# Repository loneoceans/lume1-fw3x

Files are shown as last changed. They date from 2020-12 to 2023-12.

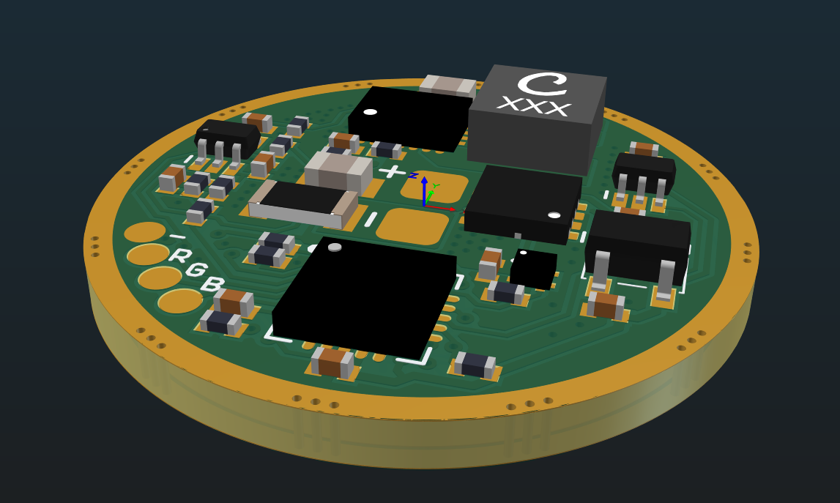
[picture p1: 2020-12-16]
physical/Rev B/lume1_fw3x_AssemblyRender2.png

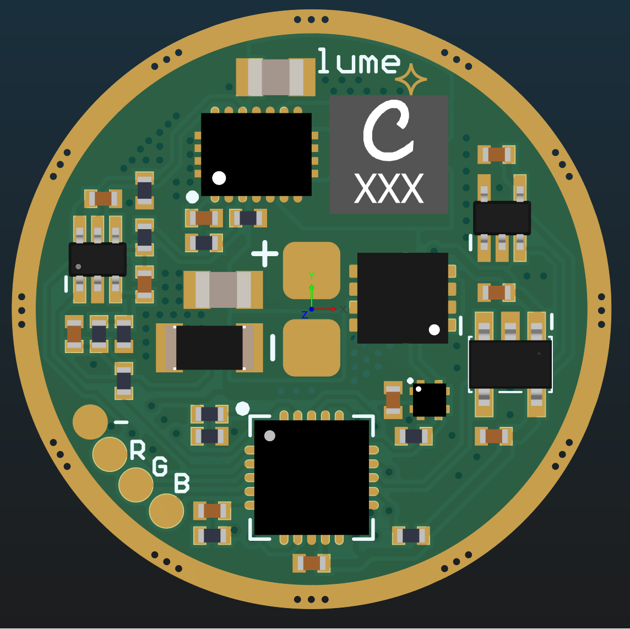
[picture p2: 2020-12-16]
physical/Rev B/lume1_fw3x_AssemblyRender1.png

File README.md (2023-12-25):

# lume1-fw3x-anduril
>**Update Dec 2023**
>
>LUME1-FW3X support has been added to the main Anduril repository here: https://github.com/ToyKeeper/anduril/tree/trunk/hw/lumintop/fw3x-lume1
>
>This repository is deprecated, please visit the link above for fresh builds of the newest version of Anduril.

Anduril 1 & 2 firmware (Atmel Studio 7) for Lume1-FW3X Driver

Hardware Revision B (lastest driver PCB has date 06/20)

lume1 Driver

* For more information: www.lonoceans.com/labs/
* Anduril by TK: https://launchpad.net/flashlight-firmware
* Community thread: http://budgetlightforum.com/node/71616

OSH

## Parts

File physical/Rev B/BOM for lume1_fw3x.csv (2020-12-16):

Designator | Quantity | Footprint | Value | Manufactuer Primary Part Number | Alternate Part Number | Description
C1 | 1 | 0402 CAPACITOR | 220p 50V X5R 402 | UMK105BJ221KV-F | CC0402KRX7R9BB221 | 0402 Capacitor
C2, C3, C4, C5 | 4 | 0402 CAPACITOR | 0.1u 16V X7R 402 | CL05B104KO5NFNC | CL05B104KO5NFNC | 0402 Capacitor
C6 | 1 | 0402 CAPACITOR | 1u 10V X6S 402 | LMK105C6105MV-F | GRM155C81A105KA12D | 0402 Capacitor
C7, C8, C9, C10 | 4 | 0402 CAPACITOR | 2.2u 10V X5R 402 | LMK105BJ225MV-F | GRM155C81E225ME11D | 0402 Capacitor
C11, C12 | 2 | 0805 CAPACITOR | 47u 10V 0805 X5R | C2012X5R1A476M125A | GRM21BR61A476ME15L | 0805 Capacitor
L1 | 1 | XFL4020 INDUCTOR | Inductor Coilcraft XFL | XGL4020-152MEC |  | Coilcraft DCR Shielded Power Inductor
Q1 | 1 | POWERPAK 1212-8S CD DUAL | 25V 30A Dual Common Drain MOSFET | SISF02DN-T1-GE3 | SISF00DN-T1-GE3 | Common Drain Dual N-Channel MOSFET
R1 | 1 | 1206 RESISTOR | 20mR 1206 1% 1W | LVT12R0200FER |  | 1206 Metal Element Resistor
R2 | 1 | 0402 RESISTOR | 100R 1% 402 | RC0402FR-07100RL |  | 0402 1% Resistor
R3, R4, R5, R6 | 4 | 0402 RESISTOR | 10k 1% 402 | RC0402FR-0710KL |  | 0402 1% Resistor
R7 | 1 | 0402 RESISTOR | 51k 1% 402 | RC0402FR-0751KL |  | 0402 1% Resistor
R8, R9, R10, R11 | 4 | 0402 RESISTOR | 100k 1% 402 | RC0402FR-07100KL |  | 0402 1% Resistor
R12 | 1 | 0402 RESISTOR | 249k 1% 402 | RC0402FR-07249KL |  | 0402 1% Resistor
R13 | 1 | 0402 RESISTOR | 392k 1% 402 | RC0402FR-07392KL |  | 0402 1% Resistor
U1 | 1 | VSON14 DSJ 4X3MM | Switching Regulator TPS63020 | TPS63020DSJR |  | 4A Synchronous Buck Boost Converter TI
U2 | 1 | QFN 20M1 | ATTINY1634 QFN20 4X4mm | ATTINY1634-MU-ND |  | 8-bit Atmel tinyAVR 16kB Flash
U3 | 1 | SC70-6 | Op Amp LTC2066 | LTC2066ISC6#TRMPBF |  | SC70-6 Op Amp with Shutdown
U4 | 1 | SC70-5 | Temperature Sensor MCP9700A | MCP9700AT-E/LT |  | Low-Power Linear Active Thermistor IC
U5 | 1 | SOT23-5 | Regulator TPS706 SOT23 | TPS70625DBVR |  | TPS706 SOT23-5 Voltage Regulator
U6 | 1 | QFN4 FT MICREL | MIC5019 Nfet Driver | MIC5019YFT-TR |  | High Side N FET Driver with Charge Pump

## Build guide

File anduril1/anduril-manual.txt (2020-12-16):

Anduril User Manual
-------------------

Anduril is an open-source firmware for flashlights, distributed under 
the terms of the GPL v3.  The sources can be obtained here:

  http://tiny.cc/TKAnduril
  https://bazaar.launchpad.net/~toykeeper/flashlight-firmware/trunk/files/head:/ToyKeeper/spaghetti-monster/anduril/

Quick Start
-----------

After putting a battery in the light and tightening the parts together, 
the light should quickly blink once to confirm it has power and is now 
operational.  After that, basic usage is simple:

  - Click to turn the light on or off.
  - Hold the button to change brightness.
  - Release and hold again to change brightness the other way.

That is all the user needs to know for basic use, but there are many 
more modes and features available for people who want more.

Before reading the rest of this manual, it is recommended that users 
look at the Anduril UI diagram, which should be provided along with the 
flashlight.

Ramping / Stepped Ramping Modes
-------------------------------

Anduril's normal operation mode uses a smooth ramp or a stepped ramp, 
depending on which style the user prefers.

Each ramp has its own settings -- floor (lowest level), ceiling (highest 
level), and the stepped ramp can also have a configurable number of 
steps.

There are four ways to access this mode when the light is off:

  - Click: Turn on at the memorized brightness.
  - Hold: Turn on at the floor level.  The light should give a very 
    subtle dark blink when the user can let go of the button to stay at 
    the floor, or keep holding the button to ramp up.
  - 2 clicks: Turn on at the ceiling level.
  - Click, hold: Turn on at the ceiling level, then ramp down.

While the light is on, a few basic actions are available:

  - Click: Turn off.
  - 2 clicks: Go to or from turbo (full power).
  - Hold: Change brightness (up).  If the button was released less than 
    a second ago, or if it's already at the ceiling, it goes down 
    instead.
  - Click, hold: Change brightness (down).
  - 3 clicks: Switch to the other ramp.
  - 4 clicks: Go to ramp config mode.
  - 5 clicks: Activate manual memory and save the current brightness.
  - 5 clicks, but hold the last click: Go back to automatic memory.

The "automatic" vs "manual" memory modes change the level the light goes 
to with 1 click from off.  In automatic mode, it uses the last 
brightness the user ramped to.  In manual mode, it uses the brightness 
the user explicitly saved with 5 clicks.

Other Modes
-----------

Anduril has several other modes too.  To access these, press the button 
more than 2 times when the light is off:

  - 3 clicks: Access the blinky / utility modes.
  - Click, click, hold: Access the strobe modes.
  - 4 clicks: Lockout mode.
  - 5 clicks: Momentary mode.
  - 6 clicks: Muggle mode.

Blinky / Utility Modes
----------------------

Click 3 times from Off to access Anduril's blinky / utility modes.  This 
always starts at battery check and the user can proceed to other blinky 
modes from there.  The sequence is:

  1. Battery check.
  2. Sunset mode.
  3. Beacon mode.
  4. Temperature check.

In all of these modes, some basic actions are available:

  - Click: Turn off.
  - 2 clicks: Next blinky mode.

Additionally, in beacon and temperature check modes:

  - 4 clicks: Go to the beacon config mode or thermal config mode.

In more detail, this is what each blinky / utility mode does:

  1. Battery check.

     Blinks out the battery voltage per cell.  Full is 4.2V, empty is 
     about 3.0V.  The light blinks the whole-number digit first, pauses, 
     then blinks out the "tenths" digit.  Then a longer pause, and it 
     repeats.
     So for 4.2V, it would be "blink-blink-blink-blink .. blink-blink".

     A "zero" digit is represented by a very quick blink.

  2. Sunset mode.

     This starts at a low level, then dims gradually for an hour, and 
     then shuts off.  It is intended for use when going to bed.

  3. Beacon mode.

     Blinks at a slow speed.  The light stays on for half a second, and 
     then stays off until the next blink.  The brightness and the number 
     of seconds between pulses are configurable:

       - Brightness is the user's last-ramped level, so set this in 
         ramping mode before starting beacon mode.

       - Speed is configured in beacon config mode.  Click 4 times to 
         enter beacon config mode, wait for the light to stutter, then 
         click to enter the number of seconds per blink.  For example, 
         to do a 10-second alpine beacon, click 10 times.

  4. Temperature check.

     Blinks out the current temperature in degrees C.  This number 
     should be pretty close to what a real thermometer says.  If not, it 
     would be a good idea to click 4 times to enter thermal config mode, 
     and calibrate the sensor.

     Thermal config mode has two settings:

     - Current temperature.  Click once per degree C to calibrate the 
       sensor.  For example, if the ambient temperature is 21 C, then 
       click 21 times.

     - Temperature limit.  This sets the maximum temperature the light 
       can reach before it will start doing thermal regulation to keep 
       itself from overheating.  Click once per degree C above 30.  For 
       example, to set the limit to 50 C, click 20 times.  The default 
       is 45 C, and the highest value it will allow is 70 C.

Strobe / Mood Modes
-------------------

Anduril includes a few extra modes for a variety of purposes:

  - Candle mode
  - Bike flasher
  - Party strobe
  - Tactical strobe
  - Lightning storm mode

Click 3 times from Off to access these, but hold the third click for a 
moment.  Click, click, hold.  The last-used strobe mode is remembered, 
so it will return to whichever one you used last.

In all of these modes, a few actions are available:

  - Click: Turn off.
  - 2 Clicks: Next strobe / mood mode.
  - Hold: Increase brightness, or strobe faster.  (except lightning)
  - Click, hold: Decrease brightness, or strobe slower.  (except lightning)

Additionally, candle mode has one more action:

  - 3 clicks: Add 30 minutes to the timer.

In more detail, here is what each mode does:

  - Candle mode

    Brightness changes randomly in a pattern resembling a candle flame.  
    If a timer is set, it will run until the timer expires, then get 
    dimmer for one minute, then sputter and turn itself off.  Without a 
    timer, candle mode runs until the user turns it off.  Brightness is 
    configurable.

  - Bike flasher

    Runs at a medium level, but stutters to a brighter level once per 
    second.  Designed to be more visible than a normal ramping mode, but 
    otherwise works mostly the same.  Brightness is configurable.

  - Party strobe

    Motion-freezing strobe light.  Can be used to freeze spinning fans 
    and falling water.  Speed is configurable.

  - Tactical strobe

    Disorienting strobe light.  Can be used to irritate people.  Speed 
    is configurable, and the duty cycle is always 33%.

  - Lightning storm mode

    Flashes at random brightness and random speed to simulate lightning 
    strikes during a busy lightning storm.  Do not look directly at the 
    flashlight when this mode is running, because it may suddenly go to 
    full power without warning.

Lockout Mode
------------

Click 4 times from Off to enter Lockout mode.  This makes the light safe 
to carry in a pocket or a bag or anywhere else the button might be 
pressed by accident.

To exit lockout mode, click 4 times.  The light should blink briefly and 
then return to the regular "off" mode.

Lockout mode also doubles as a momentary moon mode, so the user can do 
quick tasks without having to unlock the light.  The brightness in 
lockout mode has two levels:

  - Hold: light up at the floor level of the current ramp.
  - Click, Hold: light up at the floor level of the other ramp.

Momentary Mode
--------------

Click 5 times from Off to enter Momentary mode.  This locks the 
flashlight into a single-mode interface where the LEDs are only on when 
the button is held down.  It is intended for Morse code, light painting, 
and other tasks where the light should be on only for a short time and 
probably in a pattern.

Momentary mode does either a steady brightness level or a strobe.  To 
select which one, go to the mode you want to use, adjust the brightness 
and speed and other settings, then turn the light off.  Then click 5 
times to enter momentary mode.

Supported momentary modes are steady (normal ramping mode) and strobes 
(everything in the "strobe" mode group).

In steady mode, brightness is the last-ramped level, so adjust that 
before entering momentary mode.

In momentary strobe mode, the settings are copied from the last-used 
strobe mode, such as party strobe, tactical strobe, or lightning.

To exit this mode, physically disconnect power by unscrewing the tailcap 
or battery tube.

Muggle Mode
-----------

Click 6 times from Off to enter Muggle mode.  This is a simpler and 
less-bright interface which makes the light relatively safe to lend to 
children or other people who could use the light unsafely.

In Muggle mode, there are only a few available actions:

  - Click: Turn the light on or off.
  - Hold: Change brightness.
  - 6 clicks: Exit Muggle mode.

The brightness in this mode usually goes from about 10 lm to 300 lm.

Muggle mode is remembered even after changing the battery.  This helps 
prevent children from exiting the mode by unscrewing the tailcap.  
However, be sure to supervise children whenever they are using any 
powerful tools, including a bright flashlight.

Note: If the light steps down in muggle mode, it probably needs to have 
the temperature sensor calibrated.  Use thermal config mode to do this.

Configuration Modes
-------------------

Every config mode has the same interface.  The menu has one or more 
options the user can configure, and it will go through them in order.  
For each menu item, the light will follow the same pattern:

  - Blink one or more times, corresponding to the item number.

  - Stutter or "buzz" quickly between two brightness levels for a few 
    seconds.  This indicates that the user can click one or more times 
    to enter a number.  It will keep buzzing until the user stops 
    clicking, so there is no need to hurry.

  - Pause, and then go to the next option.

After the light has gone through all of the menu options, it should 
return to whatever mode the light was in before entering the config 
mode.

If the user doesn't press a button during a menu item's "buzz" phase, 
that item remains unchanged from its previous value.

Ramp Config Mode
----------------

While the light is on in a ramping mode, click 4 times to enter the 
config mode for the current ramp.

For smooth ramping mode, there are two menu options:

  1. Floor.  (default = 1/150)
  2. Ceiling.  (default = 120/150)

For the stepped ramping mode, there are three menu options:

  1. Floor.  (default = 20/150)
  2. Ceiling.  (default = 120/150)
  3. Number of steps.  (default = 7)

To configure the floor level, click the button equal to the number of 
ramp levels (out of 150) at which the floor should be.  To set the 
lowest possible level, click once.

To configure the ceiling level, each click goes one level lower.  So 1 
click sets the highest possible level, 2 clicks is the 2nd-highest, 3 
clicks is the 3rd-highest level, etc.  To set the default of 120/150, 
click 31 times.

When configuring the number of steps, the value can be anything from 2 
to 150.

Protection Features
-------------------

Anduril includes low voltage protection (LVP) and thermal regulation.

LVP makes the light step down to a lower level when the battery is low, 
and if the light is already at the lowest level, it shuts itself off.  
This activates at 2.8V.  LVP adjustments happen suddenly, in large 
steps.

Thermal regulation attempts to keep the light from overheating, and 
otherwise adjusts output to stay as close as possible to the 
user-configured temperature limit.  Thermal adjustments happen 
gradually, in steps so small they are difficult for humans to perceive.

Aux LEDs / Button LEDs
----------------------

Some lights have aux LEDs or button LEDs.  These can be configured to do 
different things while the main emitters are off.  There is one aux LED 
mode for the regular "off" mode, and another aux LED mode for "lockout" 
mode.  This allows the user to see at a glance whether the light is 
locked.

Aux LED modes typically include:

  - Off
  - Low
  - High
  - Blinking

To configure the aux LEDs, go to the mode you want to configure and then 
click the button a few times:

  - Off mode: 7 clicks.
  - Lockout mode: 3 clicks.

This should change the aux LEDs to the next mode supported on this 
light.

If the aux LEDs can change color, there are additional actions to change 
the color.  It is the same as above, but hold the button on the last 
click and then let go when the desired color is reached.

  - Off mode: 7 clicks, but hold the last click.
  - Lockout mode: 3 clicks, but hold the last click.

For lights with a button LED, the button LED typically stays on while 
the main emitters are on.  Its brightness level is set in a way which 
mirrors the main LED -- off, low, or high.

For lights with front-facing aux LEDs, the aux LEDs typically stay off 
when the main emitters are on, and when the light is otherwise awake.  
The aux LEDs on most lights only turn on when the light is asleep.

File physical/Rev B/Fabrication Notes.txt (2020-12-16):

Contact: Guangyan, loneoceans@gmail.com
Project: lume1_fw3x_revb
Date: 30 Jun 2020

========= FABRICATION SPECIFICATIONS ========= 
Layers 			2
Material 		FR-4
PCB Finished Thickness	1.6mm
Finished Copper Weight	1oz
Minimum Trace Width	6mil
Minimum Spacing		6mil
Minimum Via Drill	10mil (0.254mm)
Minimum Annular Ring	5mil
Via Process		Mix of Tented and Untented
Number of Drills	149
Silkscreen Min Width	4mil
Silkscreen Colour	White
Soldermask Colour	Red
Surface Finish		ENIG 1u"
Assembly		Only Top Side
Components		33
Unique BOM Items	20
Solder Paste		Leaded Solder
RoHS			Not Required
Board Type		Individual Route-Out
===============================================

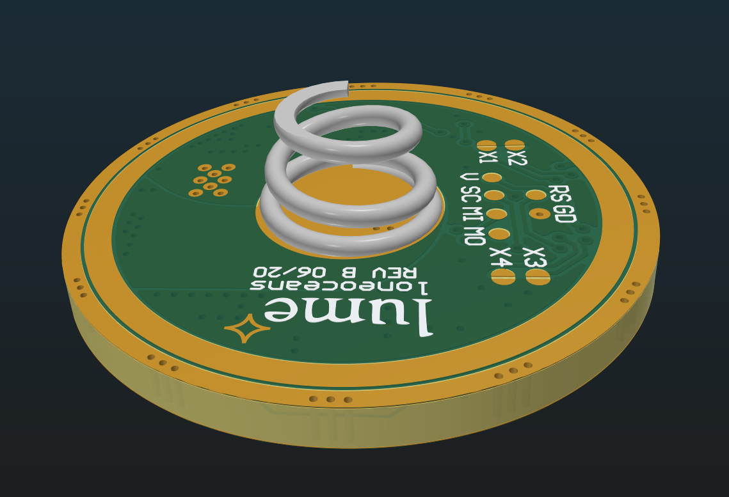
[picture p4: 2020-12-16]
physical/Rev B/lume1_fw3x_AssemblyRender3.png

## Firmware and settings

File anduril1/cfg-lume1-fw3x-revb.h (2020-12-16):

/* lume1 for FW3x config options for Anduril
 * Constant current Buck-Boost + FET driver
 * For more information: www.loneoceans.com/labs/
 * Datasheets:
 * - 1634: http://ww1.microchip.com/downloads/en/DeviceDoc/Atmel-8303-8-bit-AVR-Microcontroller-tinyAVR-ATtiny1634_Datasheet.pdf
 * - Manual: https://bazaar.launchpad.net/~toykeeper/flashlight-firmware/fsm/view/head:/ToyKeeper/spaghetti-monster/anduril/anduril-manual.txt
 * - Repository: https://code.launchpad.net/~toykeeper/flashlight-firmware
 */

#include "hwdef-lume1-fw3x-revb.h"
// ATTINY: 1634

// ##################################################
// ##               THERMAL CONFIG                 ##
// ##################################################

// NOTES: Anduril1 updated with Enable Pin support handling
// NOTES: Anduril1 updated to support external temp sensor handling (see HWCFG for formulas)

#define USE_THERMAL_REGULATION

// set this light for 50C thermal ceiling
#undef DEFAULT_THERM_CEIL
#define DEFAULT_THERM_CEIL 50
//#define MAX_THERM_CEIL 70 // default

// drop from turbo at therm_ceil+TURBO_TEMP_EXTRA
#define TURBO_TEMP_EXTRA 3 // in celsius

// optional, makes initial turbo step-down faster so first peak isn't as hot
// FET mode can run very very hot, so be extra careful
//#define THERM_HARD_TURBO_DROP

// stop panicking at ~85% regulated power or ~750 lm
#define THERM_FASTER_LEVEL 140

// respond to thermal changes faster
#define THERMAL_WARNING_SECONDS 3
#define THERMAL_UPDATE_SPEED 1
#define THERM_PREDICTION_STRENGTH 4
//#define THERM_RESPONSE_MAGNITUDE 128

// easier access to thermal config mode, similar to Emisar, Noctigon
#define USE_TENCLICK_THERMAL_CONFIG

#define THERM_CAL_OFFSET 0  // not needed due to external sensor

// do not recalibrate light temperature to 21C upon factory reset!
// Lume driver has a calibrated temperature sensor already
// modified main.c at line 2534
#define NO_TEMP_CAL_DURING_RESET


// ##################################################
// ##                 RAMP CONFIG                  ##
// ##################################################

// ../../bin/level_calc.py cube 1 149 7135 0 0.5 1000, with 0 appended to the end.
// for FET PWM (PWM2), all values are 0, except for last value of 1023
// (with max_pwm set to 1023)
#define RAMP_LENGTH 150
//#define PWM1_LEVELS 0,0,0,0,1,1,1,1,2,2,2,3,3,4,4,5,5,6,7,7,8,9,10,11,12,13,14,15,16,17,19,20,22,23,25,26,28,30,32,34,36,38,40,42,45,47,49,52,55,58,60,63,66,70,73,76,80,83,87,91,94,98,102,107,111,115,120,124,129,134,139,144,150,155,160,166,172,178,184,190,196,203,209,216,223,230,237,244,252,259,267,275,283,291,299,308,316,325,334,343,353,362,372,382,392,402,412,423,433,444,455,466,478,489,501,513,525,538,550,563,576,589,602,616,630,644,658,672,687,701,716,731,747,762,778,794,810,827,844,861,878,895,913,930,948,967,985,1004,1023,0
#define PWM1_LEVELS 1,1,1,1,2,2,2,2,3,3,3,4,4,5,5,6,6,7,8,8,9,10,11,12,13,14,15,16,17,18,20,21,23,24,26,27,29,31,33,35,37,39,41,43,45,48,50,53,56,58,61,64,67,70,74,77,80,84,88,91,95,99,103,108,112,116,121,125,130,135,140,145,150,156,161,167,173,178,184,191,197,203,210,217,223,230,238,245,252,260,268,275,283,292,300,308,317,326,335,344,353,363,372,382,392,402,413,423,434,445,456,467,478,490,502,514,526,538,551,563,576,589,603,616,630,644,658,672,687,702,717,732,747,763,778,794,811,827,844,861,878,895,913,931,949,967,985,1004,1023,0
#define PWM2_LEVELS 0,0,0,0,0,0,0,0,0,0,0,0,0,0,0,0,0,0,0,0,0,0,0,0,0,0,0,0,0,0,0,0,0,0,0,0,0,0,0,0,0,0,0,0,0,0,0,0,0,0,0,0,0,0,0,0,0,0,0,0,0,0,0,0,0,0,0,0,0,0,0,0,0,0,0,0,0,0,0,0,0,0,0,0,0,0,0,0,0,0,0,0,0,0,0,0,0,0,0,0,0,0,0,0,0,0,0,0,0,0,0,0,0,0,0,0,0,0,0,0,0,0,0,0,0,0,0,0,0,0,0,0,0,0,0,0,0,0,0,0,0,0,0,0,0,0,0,0,0,1023

#define DEFAULT_LEVEL 56
#define MAX_1x7135 77   // approximately 500mA equivalent

//#define HALFSPEED_LEVEL 14
//#define QUARTERSPEED_LEVEL 5

// turn on BuckBoost from level 1 to 149, but not 150
// Level 150 is when BuckBoost is off and FET is ON 100%
#define LED_ENABLE_PIN_LEVEL_MIN 1
#define LED_ENABLE_PIN_LEVEL_MAX 149

// the entire ramp is regulated; don't blink halfway up
#ifdef BLINK_AT_RAMP_MIDDLE
#undef BLINK_AT_RAMP_MIDDLE
#endif

// don't slow down at low levels; this isn't that sort of light
// (it needs to stay at full speed for the 10-bit PWM to work)
#ifdef USE_DYNAMIC_UNDERCLOCKING
#undef USE_DYNAMIC_UNDERCLOCKING
#endif

#define RAMP_SMOOTH_FLOOR 1
#define RAMP_SMOOTH_CEIL 149	// Level 150 is when BuckBoost is off and FET is ON 100%
// 10, 30, [50], 70, 90, 110, 130
#define RAMP_DISCRETE_FLOOR 10
#define RAMP_DISCRETE_CEIL RAMP_SMOOTH_CEIL
#define RAMP_DISCRETE_STEPS 7

// Muggle mode: Goal from about ~10 lumens to about ~300+ lumens
// In this case, ramp number 99 is about 1A to the driver
#define MUGGLE_FLOOR RAMP_DISCRETE_FLOOR
#define MUGGLE_CEILING 99

// ##################################################
// ##              AUX & MISC CONFIG               ##
// ##################################################

// this light has three aux LED channels: R, G, B
#define USE_AUX_RGB_LEDS

// it has no independent LED in the button unlike emisar d4
//#define USE_BUTTON_LED

// the aux LEDs are front-facing, so turn them off while main LEDs are on
// TODO: the whole "indicator LED" thing needs to be refactored into
//       "aux LED(s)" and "button LED(s)" since they work a bit differently
#ifdef USE_INDICATOR_LED_WHILE_RAMPING
#undef USE_INDICATOR_LED_WHILE_RAMPING
#endif
#define RGB_LED_OFF_DEFAULT 0x18  // low, voltage
#define RGB_LED_LOCKOUT_DEFAULT 0x37  // blinking, rainbow

// enable blinking aux LEDs
#define TICK_DURING_STANDBY
#define STANDBY_TICK_SPEED 3  // every 0.128 s
//#define STANDBY_TICK_SPEED 4  // every 0.256 s
//#define STANDBY_TICK_SPEED 5  // every 0.512 s

// slow down party strobe; this driver can't pulse for too short a time
#define PARTY_STROBE_ONTIME 4

//#define THERM_CAL_OFFSET 0	// was 5 from Noctigon

// attiny1634 has enough space to smooth out voltage readings
#define USE_VOLTAGE_LOWPASS

// can't reset the normal way because power is connected before the button
#define USE_SOFT_FACTORY_RESET

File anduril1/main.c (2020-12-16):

/*
 * Anduril: Narsil-inspired UI for SpaghettiMonster.
 * (Anduril is Aragorn's sword, the blade Narsil reforged)
 *
 * Copyright (C) 2017-2019 Selene Scriven
 *
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
 * You should have received a copy of the GNU General Public License
 * along with this program.  If not, see <http://www.gnu.org/licenses/>.
 */

/*
 * For Flashing
 * 8 MHz, 64ms boot delay, enable flashing, disable everything else
 * Use low fuse 0xD2 for 4ms startup delay
 *           or 0xE2 for 64ms, useful on twisty light 
 * Use high fuse 0xDE for BOD 1.8V
 *            or 0xDF for no BOS
 * Recommend low, high as 0xE2 and 0xDE for lume1_FW3x
 */

/* Firmware used: https://bazaar.launchpad.net/~toykeeper/flashlight-firmware/noctigon-k1/
 * files/head:/ToyKeeper/spaghetti-monster/anduril 
 * Version: Feb 2020
 * Modified slightly for use with lume1 architecture.
 */

/********* User-configurable options *********/
// Anduril config file name (set it here or define it at the gcc command line)

#define ATTINY 1634
#define CONFIGFILE cfg-lume1-fw3x-revb.h    // For Lume1 Driver for FW3x (Rev B)

#define USE_LVP  // FIXME: won't build when this option is turned off

// parameters for this defined below or per-driver
#define USE_FACTORY_RESET
//#define USE_SOFT_FACTORY_RESET  // only needed on models which can't use hold-button-at-boot

// dual-switch support (second switch is a tail clicky)
// (currently incompatible with factory reset)
//#define START_AT_MEMORIZED_LEVEL

// include a function to blink out the firmware version
#define USE_VERSION_CHECK

// short blip when crossing from "click" to "hold" from off
// (helps the user hit moon mode exactly, instead of holding too long
//  or too short)
#define MOON_TIMING_HINT  // only applies if B_TIMING_ON == B_PRESS_T
// short blips while ramping
#define BLINK_AT_RAMP_MIDDLE
//#define BLINK_AT_RAMP_FLOOR
#define BLINK_AT_RAMP_CEILING
//#define BLINK_AT_STEPS  // whenever a discrete ramp mode is passed in smooth mode

// ramp down via regular button hold if a ramp-up ended <1s ago
// ("hold, release, hold" ramps down instead of up)
#define USE_REVERSING

// add a runtime option to switch between automatic memory (default)
// and manual memory (only available if compiled in)
// (manual memory makes 1-click-from-off start at the same level each time)
// (the level can be set explicitly with 5 clicks from on,
// or the user can go back to automatic with click-click-click-click-hold)
#define USE_MANUAL_MEMORY

// battery readout style (pick one)
#define BATTCHECK_VpT
//#define BATTCHECK_8bars  // FIXME: breaks build
//#define BATTCHECK_4bars  // FIXME: breaks build

// enable/disable various strobe modes
#define USE_BIKE_FLASHER_MODE
#define USE_PARTY_STROBE_MODE
#define USE_TACTICAL_STROBE_MODE
#define USE_LIGHTNING_MODE
#define USE_CANDLE_MODE

// enable sunset (goodnight) mode
#define USE_GOODNIGHT_MODE
#define GOODNIGHT_TIME  60  // minutes (approximately)
#define GOODNIGHT_LEVEL 24  // ~11 lm

// enable beacon mode
#define USE_BEACON_MODE

// enable momentary mode
#define USE_MOMENTARY_MODE

//Muggle mode for easy UI
#define USE_MUGGLE_MODE

// make the ramps configurable by the user
#define USE_RAMP_CONFIG

// boring strobes nobody really likes, but sometimes flashlight companies want
// (these replace the fun strobe group,
//  so don't enable them at the same time as any of the above strobes)
//#define USE_POLICE_STROBE_MODE
//#define USE_SOS_MODE
//#define USE_SOS_MODE_IN_FF_GROUP  // put SOS in the "boring strobes" mode
//#define USE_SOS_MODE_IN_BLINKY_GROUP  // put SOS in the blinkies mode group

// cut clock speed at very low modes for better efficiency
// (defined here so config files can override it)
#define USE_DYNAMIC_UNDERCLOCKING

/***** specific settings for known driver types *****/
#include "tk.h"
#include incfile(CONFIGFILE)


// brightness to use when no memory is set
#ifndef DEFAULT_LEVEL
#define DEFAULT_LEVEL MAX_1x7135
#endif

// thermal properties, if not defined per-driver
#ifndef MIN_THERM_STEPDOWN
#define MIN_THERM_STEPDOWN MAX_1x7135  // lowest value it'll step down to
#endif
#ifndef THERM_FASTER_LEVEL
    #ifdef MAX_Nx7135
    #define THERM_FASTER_LEVEL MAX_Nx7135  // throttle back faster when high
    #else
    #define THERM_FASTER_LEVEL (RAMP_SIZE*4/5)  // throttle back faster when high
    #endif
#endif
#ifdef USE_THERMAL_REGULATION
#define USE_SET_LEVEL_GRADUALLY  // isn't used except for thermal adjustments
#endif


/********* Configure SpaghettiMonster *********/
#define USE_DELAY_ZERO
#define USE_RAMPING
#ifndef RAMP_LENGTH
#define RAMP_LENGTH 150  // default, if not overridden in a driver cfg file
#endif
#define MAX_BIKING_LEVEL 120  // should be 127 or less
#define USE_BATTCHECK

#if defined(USE_MUGGLE_MODE)
#ifndef MUGGLE_FLOOR
#define MUGGLE_FLOOR 22
#endif
#ifndef MUGGLE_CEILING
#define MUGGLE_CEILING (MAX_1x7135+20)
#endif
#endif
#define USE_IDLE_MODE  // reduce power use while awake and no tasks are pending

// full FET strobe can be a bit much...  use max regulated level instead,
// if there's a bright enough regulated level
#ifndef STROBE_BRIGHTNESS
#ifdef MAX_Nx7135
#define STROBE_BRIGHTNESS MAX_Nx7135
#else
#define STROBE_BRIGHTNESS MAX_LEVEL
#endif
#endif

#if defined(USE_CANDLE_MODE) || defined(USE_BIKE_FLASHER_MODE) || defined(USE_PARTY_STROBE_MODE) || defined(USE_TACTICAL_STROBE_MODE) || defined(USE_LIGHTNING_MODE)
#define USE_STROBE_STATE
#endif

#if defined(USE_POLICE_STROBE_MODE) || defined(USE_SOS_MODE_IN_FF_GROUP)
#define USE_BORING_STROBE_STATE
#endif

// auto-detect how many eeprom bytes
#define USE_EEPROM
typedef enum {
    ramp_style_e,
    #ifdef USE_RAMP_CONFIG
    ramp_smooth_floor_e,
    ramp_smooth_ceil_e,
    ramp_discrete_floor_e,
    ramp_discrete_ceil_e,
    ramp_discrete_steps_e,
    #endif
    #ifdef USE_MANUAL_MEMORY
    manual_memory_e,
    #endif
    #ifdef USE_TINT_RAMPING
    tint_e,
    #endif
    #ifdef USE_STROBE_STATE
    strobe_type_e,
    #endif
    #if defined(USE_PARTY_STROBE_MODE) || defined(USE_TACTICAL_STROBE_MODE)
    strobe_delays_0_e,
    strobe_delays_1_e,
    #endif
    #ifdef USE_BIKE_FLASHER_MODE
    bike_flasher_brightness_e,
    #endif
    #ifdef USE_BEACON_MODE
    beacon_seconds_e,
    #endif
    #ifdef USE_MUGGLE_MODE
    muggle_mode_active_e,
    #endif
    #ifdef USE_THERMAL_REGULATION
    therm_ceil_e,
    therm_cal_offset_e,
    #endif
    #ifdef USE_INDICATOR_LED
    indicator_led_mode_e,
    #endif
    #ifdef USE_AUX_RGB_LEDS
    rgb_led_off_mode_e,
    rgb_led_lockout_mode_e,
    #endif
    eeprom_indexes_e_END
} eeprom_indexes_e;
#define EEPROM_BYTES eeprom_indexes_e_END

#ifdef START_AT_MEMORIZED_LEVEL
#define USE_EEPROM_WL
#define EEPROM_WL_BYTES 1
#endif

// auto-configure other stuff...
#if defined(USE_LIGHTNING_MODE) || defined(USE_CANDLE_MODE)
#define USE_PSEUDO_RAND
#endif

#if defined(USE_CANDLE_MODE)
#ifndef USE_TRIANGLE_WAVE
#define USE_TRIANGLE_WAVE
#endif
#endif

#ifdef USE_SOFT_FACTORY_RESET
#define USE_REBOOT
#endif

#include "spaghetti-monster.h"


// configure the timing of turning on/off in regular ramp mode
// press: react as soon as the button is pressed
#define B_PRESS_T 0
// release: react as soon as the button is released
#define B_RELEASE_T 1
// timeout: react as soon as we're sure the user isn't doing a double-click
#define B_TIMEOUT_T 2
// defaults are release on, timeout off
#ifndef B_TIMING_ON
//#define B_TIMING_ON B_PRESS_T
#define B_TIMING_ON B_RELEASE_T
#endif
#ifndef B_TIMING_OFF
//#define B_TIMING_OFF B_RELEASE_T
#define B_TIMING_OFF B_TIMEOUT_T
#endif


// FSM states
uint8_t off_state(Event event, uint16_t arg);
// simple numeric entry config menu
uint8_t config_state_base(Event event, uint16_t arg,
                          uint8_t num_config_steps,
                          void (*savefunc)());
#define MAX_CONFIG_VALUES 3
uint8_t config_state_values[MAX_CONFIG_VALUES];
// ramping mode and its related config mode
uint8_t steady_state(Event event, uint16_t arg);
#ifdef USE_RAMP_CONFIG
uint8_t ramp_config_state(Event event, uint16_t arg);
#endif
#ifdef USE_TINT_RAMPING
// not actually a mode, more of a fallback under other modes
uint8_t tint_ramping_state(Event event, uint16_t arg);
#endif
// party and tactical strobes
#ifdef USE_STROBE_STATE
uint8_t strobe_state(Event event, uint16_t arg);
#endif
#ifdef USE_BORING_STROBE_STATE
uint8_t boring_strobe_state(Event event, uint16_t arg);
volatile uint8_t boring_strobe_type = 0;
void sos_blink(uint8_t num, uint8_t dah);
#define NUM_BORING_STROBES 2
#endif
#ifdef USE_BATTCHECK
uint8_t battcheck_state(Event event, uint16_t arg);
#endif
#ifdef USE_THERMAL_REGULATION
#define USE_BLINK_NUM
uint8_t tempcheck_state(Event event, uint16_t arg);
uint8_t thermal_config_state(Event event, uint16_t arg);
#endif
#ifdef USE_GOODNIGHT_MODE
// 1-hour ramp down from low, then automatic off
uint8_t goodnight_state(Event event, uint16_t arg);
#endif
#ifdef USE_BEACON_MODE
// beacon mode and its related config mode
uint8_t beacon_state(Event event, uint16_t arg);
uint8_t beacon_config_state(Event event, uint16_t arg);
#endif
#ifdef USE_SOS_MODE_IN_BLINKY_GROUP
// automatic SOS emergency signal
uint8_t sos_state(Event event, uint16_t arg);
#endif
// soft lockout
#define MOON_DURING_LOCKOUT_MODE
// if enabled, 2nd lockout click goes to the other ramp's floor level
#define LOCKOUT_MOON_FANCY
uint8_t lockout_state(Event event, uint16_t arg);
#ifdef USE_MOMENTARY_MODE
// momentary / signalling mode
uint8_t momentary_state(Event event, uint16_t arg);
uint8_t momentary_mode = 0;  // 0 = ramping, 1 = strobe
uint8_t momentary_active = 0;  // boolean, true if active *right now*
#endif
#ifdef USE_MUGGLE_MODE
// muggle mode, super-simple, hard to exit
uint8_t muggle_state(Event event, uint16_t arg);
uint8_t muggle_mode_active = 0;
#endif

// general helper function for config modes
uint8_t number_entry_state(Event event, uint16_t arg);
// return value from number_entry_state()
volatile uint8_t number_entry_value;

void blink_confirm(uint8_t num);
void blip();
#if defined(USE_INDICATOR_LED) && defined(TICK_DURING_STANDBY)
void indicator_blink(uint8_t arg);
#endif
#if defined(USE_AUX_RGB_LEDS) && defined(TICK_DURING_STANDBY)
uint8_t setting_rgb_mode_now = 0;
void rgb_led_update(uint8_t mode, uint8_t arg);
void rgb_led_voltage_readout(uint8_t bright);
/*
 * 0: R
 * 1: RG
 * 2:  G
 * 3:  GB
 * 4:   B
 * 5: R B
 * 6: RGB
 * 7: rainbow
 * 8: voltage
 */
const PROGMEM uint8_t rgb_led_colors[] = {
    0b00000001,  // 0: red
    0b00000101,  // 1: yellow
    0b00000100,  // 2: green
    0b00010100,  // 3: cyan
    0b00010000,  // 4: blue
    0b00010001,  // 5: purple
    0b00010101,  // 6: white
};
#define RGB_LED_NUM_COLORS 10
#define RGB_LED_NUM_PATTERNS 4
#ifndef RGB_LED_OFF_DEFAULT
//#define RGB_LED_OFF_DEFAULT 0x18  // low, voltage
#define RGB_LED_OFF_DEFAULT 0x17  // low, rainbow
#endif
#ifndef RGB_LED_LOCKOUT_DEFAULT
#define RGB_LED_LOCKOUT_DEFAULT 0x37  // blinking, rainbow
#endif
#ifndef RGB_RAINBOW_SPEED
#define RGB_RAINBOW_SPEED 0x0f  // change color every 16 frames
#endif
uint8_t rgb_led_off_mode = RGB_LED_OFF_DEFAULT;
uint8_t rgb_led_lockout_mode = RGB_LED_LOCKOUT_DEFAULT;
#endif

#ifdef USE_FACTORY_RESET
void factory_reset();
#endif

// remember stuff even after battery was changed
void load_config();
void save_config();
#ifdef START_AT_MEMORIZED_LEVEL
void save_config_wl();
#endif

// default ramp options if not overridden earlier per-driver
#ifndef RAMP_STYLE
#define RAMP_STYLE 0  // smooth default
#endif
#ifndef RAMP_SMOOTH_FLOOR
  #define RAMP_SMOOTH_FLOOR 1
#endif
#ifndef RAMP_SMOOTH_CEIL
  #if PWM_CHANNELS == 3
    #define RAMP_SMOOTH_CEIL MAX_Nx7135
  #else
    #define RAMP_SMOOTH_CEIL MAX_LEVEL - 30
  #endif
#endif
#ifndef RAMP_DISCRETE_FLOOR
  #define RAMP_DISCRETE_FLOOR 20
#endif
#ifndef RAMP_DISCRETE_CEIL
  #define RAMP_DISCRETE_CEIL RAMP_SMOOTH_CEIL
#endif
#ifndef RAMP_DISCRETE_STEPS
  #define RAMP_DISCRETE_STEPS 7
#endif

// mile marker(s) partway up the ramp
// default: blink only at border between regulated and FET
#ifdef BLINK_AT_RAMP_MIDDLE
  #if PWM_CHANNELS >= 3
    #ifndef BLINK_AT_RAMP_MIDDLE_1
      #define BLINK_AT_RAMP_MIDDLE_1 MAX_Nx7135
      #ifndef BLINK_AT_RAMP_MIDDLE_2
      #define BLINK_AT_RAMP_MIDDLE_2 MAX_1x7135
      #endif
    #endif
  #else
    #ifndef BLINK_AT_RAMP_MIDDLE_1
    #define BLINK_AT_RAMP_MIDDLE_1 MAX_1x7135
    #endif
  #endif
#endif

// brightness control
uint8_t memorized_level = DEFAULT_LEVEL;
#ifdef USE_MANUAL_MEMORY
uint8_t manual_memory = 0;
#endif
// smooth vs discrete ramping
volatile uint8_t ramp_style = RAMP_STYLE;  // 0 = smooth, 1 = discrete
volatile uint8_t ramp_smooth_floor = RAMP_SMOOTH_FLOOR;
volatile uint8_t ramp_smooth_ceil = RAMP_SMOOTH_CEIL;
volatile uint8_t ramp_discrete_floor = RAMP_DISCRETE_FLOOR;
volatile uint8_t ramp_discrete_ceil = RAMP_DISCRETE_CEIL;
volatile uint8_t ramp_discrete_steps = RAMP_DISCRETE_STEPS;
uint8_t ramp_discrete_step_size;  // don't set this

#ifdef USE_INDICATOR_LED
    // bits 2-3 control lockout mode
    // bits 0-1 control "off" mode
    // modes are: 0=off, 1=low, 2=high, 3=blinking (if TICK_DURING_STANDBY enabled)
    #ifdef INDICATOR_LED_DEFAULT_MODE
    uint8_t indicator_led_mode = INDICATOR_LED_DEFAULT_MODE;
    #else
        #ifdef USE_INDICATOR_LED_WHILE_RAMPING
        //uint8_t indicator_led_mode = (1<<2) + 2;
        uint8_t indicator_led_mode = (2<<2) + 1;
        #else
        uint8_t indicator_led_mode = (3<<2) + 1;
        #endif
    #endif
#endif

// calculate the nearest ramp level which would be valid at the moment
// (is a no-op for smooth ramp, but limits discrete ramp to only the
// correct levels for the user's config)
uint8_t nearest_level(int16_t target);

#ifdef USE_THERMAL_REGULATION
// brightness before thermal step-down
uint8_t target_level = 0;
void set_level_and_therm_target(uint8_t level);
#else
#define set_level_and_therm_target(level) set_level(level)
#endif

// internal numbering for strobe modes
#ifdef USE_STROBE_STATE
typedef enum {
    #ifdef USE_PARTY_STROBE_MODE
    party_strobe_e,
    #endif
    #ifdef USE_TACTICAL_STROBE_MODE
    tactical_strobe_e,
    #endif
    #ifdef USE_LIGHTNING_MODE
    lightning_storm_e,
    #endif
    #ifdef USE_CANDLE_MODE
    candle_mode_e,
    #endif
    #ifdef USE_BIKE_FLASHER_MODE
    bike_flasher_e,
    #endif
    strobe_mode_END
} strobe_mode_te;

const int NUM_STROBES = strobe_mode_END;

// which strobe mode is active?
#ifdef USE_CANDLE_MODE
volatile strobe_mode_te strobe_type = candle_mode_e;
#else
volatile strobe_mode_te strobe_type = 0;
#endif
#endif

#if defined(USE_PARTY_STROBE_MODE) || defined(USE_TACTICAL_STROBE_MODE)
// party / tactical strobe timing
volatile uint8_t strobe_delays[] = { 41, 67 };  // party strobe 24 Hz, tactical strobe 10 Hz
#endif

// bike mode config options
#ifdef USE_BIKE_FLASHER_MODE
volatile uint8_t bike_flasher_brightness = MAX_1x7135;
#endif

#ifdef USE_CANDLE_MODE
uint8_t candle_mode_state(Event event, uint16_t arg);
uint8_t triangle_wave(uint8_t phase);
#ifndef CANDLE_AMPLITUDE
#define CANDLE_AMPLITUDE 25
#endif
#endif

#ifdef USE_BEACON_MODE
// beacon timing
volatile uint8_t beacon_seconds = 2;
#endif

#ifdef USE_VERSION_CHECK
#define USE_BLINK_DIGIT
#include "version.h"
const PROGMEM uint8_t version_number[] = VERSION_NUMBER;
uint8_t version_check_state(Event event, uint16_t arg);
#endif
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
void loop() {

    StatePtr state = current_state;

    #ifdef USE_AUX_RGB_LEDS_WHILE_ON
        if (! setting_rgb_mode_now) rgb_led_voltage_readout(1);
    #endif

    if (0) {}

    #ifdef USE_VERSION_CHECK
    else if (state == version_check_state) {
        for (uint8_t i=0; i<sizeof(version_number)-1; i++) {
            blink_digit(pgm_read_byte(version_number + i) - '0');
            nice_delay_ms(300);
        }
        // FIXME: when user interrupts with button, "off" takes an extra click
        //  before it'll turn back on, because the click to cancel gets sent
        //  to the "off" state instead of version_check_state
        //while (button_is_pressed()) {}
        //empty_event_sequence();

        set_state(off_state, 0);
    }
    #endif  // #ifdef USE_VERSION_CHECK

    #ifdef USE_STROBE_STATE
    else if ((state == strobe_state)
         #ifdef USE_MOMENTARY_MODE
         // also handle momentary strobes
         ||  ((state == momentary_state) && (momentary_mode == 1) && (momentary_active))
         #endif
         ) {
        uint8_t st = strobe_type;

        switch(st) {
            #if defined(USE_PARTY_STROBE_MODE) || defined(USE_TACTICAL_STROBE_MODE)
            #ifdef USE_PARTY_STROBE_MODE
            case party_strobe_e:
            #endif
            #ifdef USE_TACTICAL_STROBE_MODE
            case tactical_strobe_e:
            #endif
                party_tactical_strobe_mode_iter(st);
                break;
            #endif

            #ifdef USE_LIGHTNING_MODE
            case lightning_storm_e:
                lightning_storm_iter();
                break;
            #endif

            #ifdef USE_BIKE_FLASHER_MODE
            case bike_flasher_e:
                bike_flasher_iter();
                break;
            #endif
        }

    }
    #endif  // #ifdef USE_STROBE_STATE

    #ifdef USE_BORING_STROBE_STATE
    else if (state == boring_strobe_state) {
        switch(boring_strobe_type) {
            #ifdef USE_POLICE_STROBE_MODE
            case 0: // police strobe
                police_strobe_iter();
                break;
            #endif

            #ifdef USE_SOS_MODE_IN_FF_GROUP
            default: // SOS
                sos_mode_iter();
                break;
            #endif
        }
    }
    #endif  // #ifdef USE_BORING_STROBE_STATE

    #ifdef USE_BATTCHECK
    else if (state == battcheck_state) {
        battcheck();
    }
    #endif

    #ifdef USE_BEACON_MODE
    else if (state == beacon_state) {
        beacon_mode_iter();
    }
    #endif

    #ifdef USE_SOS_MODE_IN_BLINKY_GROUP
    else if (state == sos_state) {
        sos_mode_iter();
    }
    #endif

    #ifdef USE_THERMAL_REGULATION
    // TODO: blink out therm_ceil during thermal_config_state?
    else if (state == tempcheck_state) {
        blink_num(temperature);
        nice_delay_ms(1000);
    }
    #endif

    #ifdef USE_IDLE_MODE
    else {
        // doze until next clock tick
        idle_mode();
    }
    #endif

}

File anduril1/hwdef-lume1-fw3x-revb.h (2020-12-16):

#ifndef HWDEF_LUME1_FW3X_REVB_H
#define HWDEF_LUME1_FW3X_REVB_H

/* Anduril(V1) HWDEF Header
 * lume1 Driver Rev B for FW3x driver layout (attiny1634)
 * Anduril firmware was created by ToyKeeper
 *
 * www.loneoceans.com/labs/
 * https://code.launchpad.net/~toykeeper/flashlight-firmware
 *
 * Pin / Name / Function in Lume1 Rev B
 *   1    PA6   Regulated PWM (PWM1B)
 *   2    PA5   R red aux LED (PWM0B)
 *   3    PA4   G green aux LED
 *   4    PA3   B blue aux LED
 *   5    PA2   e-switch (PCINT2) 
 *   6    PA1   Jumper 1
 *   7    PA0   Jumper 2 
 *   8    GND   GND
 *   9    VCC   VCC
 *  10    PC5   Jumper 3
 *  11    PC4   Jumper 4
 *  12    PC3   RESET
 *  13    PC2   External Thermal Sensor (ADC11)
 *  14    PC1   SCK
 *  15    PC0   N/C
 *  16    PB3   FET PWM (PWM1A)
 *  17    PB2   MISO
 *  18    PB1   MOSI
 *  19    PB0   ADC5 Voltage Battery Sense (2:1 divider)
 *  20    PA7   BB_Enable
 *				ADC12   internal thermal sensor (not used for lume1)
 *
 * Main LED power uses one pin as a global Buck Boost Enable, and 
 * one pin to control the power level via PWM. Another pin is used
 * for FET control; due to hardware, FET is typically not PWMed. 
 */

#ifdef ATTINY
#undef ATTINY
#endif
#define ATTINY 1634
#include <avr/io.h>

#define PWM_CHANNELS 2
// Added for Lume1 Buck Boost Driver
#define PWM_BITS 10  // 0 to 1023 at 3.9 kHz, not 0 to 255 at 15.6 kHz
#define PWM_TOP 1023

#define SWITCH_PIN   PA2    // pin 5
#define SWITCH_PCINT PCINT2 // pin 5 pin change interrupt
#define SWITCH_PCIE  PCIE0  // PCIE0 is for PCINT[7:0]
#define SWITCH_PCMSK PCMSK0 // PCMSK0 is for PCINT[7:0]
#define SWITCH_PORT  PINA   // PINA or PINB or PINC

#define PWM1_PIN PA6        // pin 1, Buck Boost CTRL pin or 7135-eqv PWM
#define PWM1_LVL OCR1B      // OCR1A is the output compare register for PA6

#define PWM2_PIN PB3        // pin 16, FET PWM Pin, but only used as on (1023) or off (0)
#define PWM2_LVL OCR1A      // OCR1A is the output compare register for PB3

// Added for Lume1 Buck Boost Driver
#define LED_ENABLE_PIN  PA7    // pin 20, BuckBoost Enable
#define LED_ENABLE_PORT PORTA  // control port for PA7

/* // For Jumpers X1 to X4, no SW support yet
#define JUMPER1_PIN PA1
#define JUMPER2_PIN PA0
#define JUMPER3_PIN PC5
#define JUMPER4_PIN PC4
*/

/*
// average drop across diode on this hardware
// not applicable for LUME1 driver
#ifndef VOLTAGE_FUDGE_FACTOR
#define VOLTAGE_FUDGE_FACTOR 4  // add 0.20V  (measured 0.22V)
#endif
*/

#define USE_VOLTAGE_DIVIDER   // use a dedicated pin, not VCC, because VCC input is flattened
#define VOLTAGE_PIN PB0       // Pin 19  PB0  ADC5
// pin to ADC mappings are in DS table 19-4
#define VOLTAGE_ADC ADC5D  // digital input disable pin for PB1
// DIDR0/DIDR1 mappings are in DS section 19.13.5, 19.13.6
#define VOLTAGE_ADC_DIDR DIDR1  // DIDR channel for ADC5D
// DS tables 19-3, 19-4
// Bit   7     6     5      4     3    2    1    0
//     REFS1 REFS0 REFEN ADC0EN MUX3 MUX2 MUX1 MUX0
// MUX[3:0] = 0, 1, 0, 1 for ADC5 / PB0
// divided by ...
// REFS[1:0] = 0, 0 for VCC as analog reference at 2.5V
// other bits reserved
#define ADMUX_VOLTAGE_DIVIDER 0b00000101
#define ADC_PRSCL   0x06    // clk/64

// Raw ADC readings at 4.4V and 2.2V
// calibrate the voltage readout here
// estimated / calculated values are:
// [(Vbatt)*(R2/(R2+R1)) / 2.5V] * 1023
// R1 = R2 = 100kR
#ifndef ADC_44
#define ADC_44 900
#endif
#ifndef ADC_22
#define ADC_22 450
#endif

// Default ADMUX_THERM for Temperature is: 0b10001110 in tk-attiny.h
// REFS[1:0] as 10 for analog reference at internal 1.1Vref
// MUX[3:0] as 1110 for ADC'12' - temperature sensor internal

#define USE_EXTERNAL_TEMP_SENSOR
#define ADMUX_THERM_EXTERNAL_SENSOR 0b00001011  // VCC reference (2.5V), Channel PC2
// Used for Lume1 Driver: MCP9700 - T_Celsius = 100*(VOUT - 0.5V)
// ADC is 2.5V reference, 0 to 1023
// FIXME: due to floating point, this calculation takes 916 extra bytes
//        (should use an integer equivalent instead)
#define EXTERN_TEMP_FORMULA(m) (((m)-205)/4.09)
// modified fsm-adc.c line ~384 to add in reverse formula
#define EXTERN_TEMP_REVERSE_FORMULA(t) (((t)*4.09)+205) // takes t_Celsius and gives a 10-bit ADC Value 

// this driver allows for aux LEDs under the optic
#define AUXLED_R_PIN   PA5    // pin 2
#define AUXLED_G_PIN   PA4    // pin 3
#define AUXLED_B_PIN   PA3    // pin 4
#define AUXLED_RGB_PORT PORTA // PORTA or PORTB or PORTC
#define AUXLED_RGB_DDR DDRA   // DDRA or DDRB or DDRC
#define AUXLED_RGB_PUE PUEA   // PUEA or PUEB or PUEC
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

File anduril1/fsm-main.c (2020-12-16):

/*
 * fsm-main.c: main() function for SpaghettiMonster.
 *
 * Copyright (C) 2017 Selene Scriven
 *
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
 * You should have received a copy of the GNU General Public License
 * along with this program.  If not, see <http://www.gnu.org/licenses/>.
 */

#ifndef FSM_MAIN_C
#define FSM_MAIN_C

#include "fsm-main.h"

#if PWM_CHANNELS == 4
// 4th PWM channel requires manually turning the pin on/off via interrupt :(
ISR(TIMER1_OVF_vect) {
    //bitClear(PORTB, 3);
    PORTB &= 0b11110111;
    //PORTB |= 0b00001000;
}
ISR(TIMER1_COMPA_vect) {
    //if (!bitRead(TIFR,TOV1)) bitSet(PORTB, 3);
    if (! (TIFR & (1<<TOV1))) PORTB |= 0b00001000;
    //if (! (TIFR & (1<<TOV1))) PORTB &= 0b11110111;
}
#endif

#if (ATTINY == 25) || (ATTINY == 45) || (ATTINY == 85)
static inline void hw_setup() {
    // configure PWM channels
    #if PWM_CHANNELS >= 1
    DDRB |= (1 << PWM1_PIN);
    TCCR0B = 0x01; // pre-scaler for timer (1 => 1, 2 => 8, 3 => 64...)
    TCCR0A = PHASE;
    #endif
    #if PWM_CHANNELS >= 2
    DDRB |= (1 << PWM2_PIN);
    #endif
    #if PWM_CHANNELS >= 3
    // Second PWM counter is ... weird
    DDRB |= (1 << PWM3_PIN);
    TCCR1 = _BV (CS10);
    GTCCR = _BV (COM1B1) | _BV (PWM1B);
    OCR1C = 255;  // Set ceiling value to maximum
    #endif
    #if PWM_CHANNELS >= 4
    // 4th PWM channel is ... not actually supported in hardware  :(
    DDRB |= (1 << PWM4_PIN);
    //OCR1C = 255;  // Set ceiling value to maximum
    TCCR1 = 1<<CTC1 | 1<<PWM1A | 3<<COM1A0 | 2<<CS10;
    GTCCR = (2<<COM1B0) | (1<<PWM1B);
    // set up an interrupt to control PWM4 pin
    TIMSK |= (1<<OCIE1A) | (1<<TOIE1);
    #endif

    // configure e-switch
    PORTB = (1 << SWITCH_PIN);  // e-switch is the only input
    PCMSK = (1 << SWITCH_PIN);  // pin change interrupt uses this pin
}
#elif (ATTINY == 1634)
static inline void hw_setup() {
    // this gets tricky with so many pins...
    // ... so punt it to the hwdef file
    hwdef_setup();
}
#else
    #error Unrecognized MCU type
#endif


//#ifdef USE_REBOOT
static inline void prevent_reboot_loop() {
    // prevent WDT from rebooting MCU again
    MCUSR &= ~(1<<WDRF);  // reset status flag
    wdt_disable();
}
//#endif
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

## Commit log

2020-12-16 Lume1-FW3X Driver Datasheet
    Preliminary datasheet
2020-12-16 Datasheet for Lume1-FW3X driver
2020-12-16 Fabrication Package
    [BOM for lume1_fw3x.csv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]

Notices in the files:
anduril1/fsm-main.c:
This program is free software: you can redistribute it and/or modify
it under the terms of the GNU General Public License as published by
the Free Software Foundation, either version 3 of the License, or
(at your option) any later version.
